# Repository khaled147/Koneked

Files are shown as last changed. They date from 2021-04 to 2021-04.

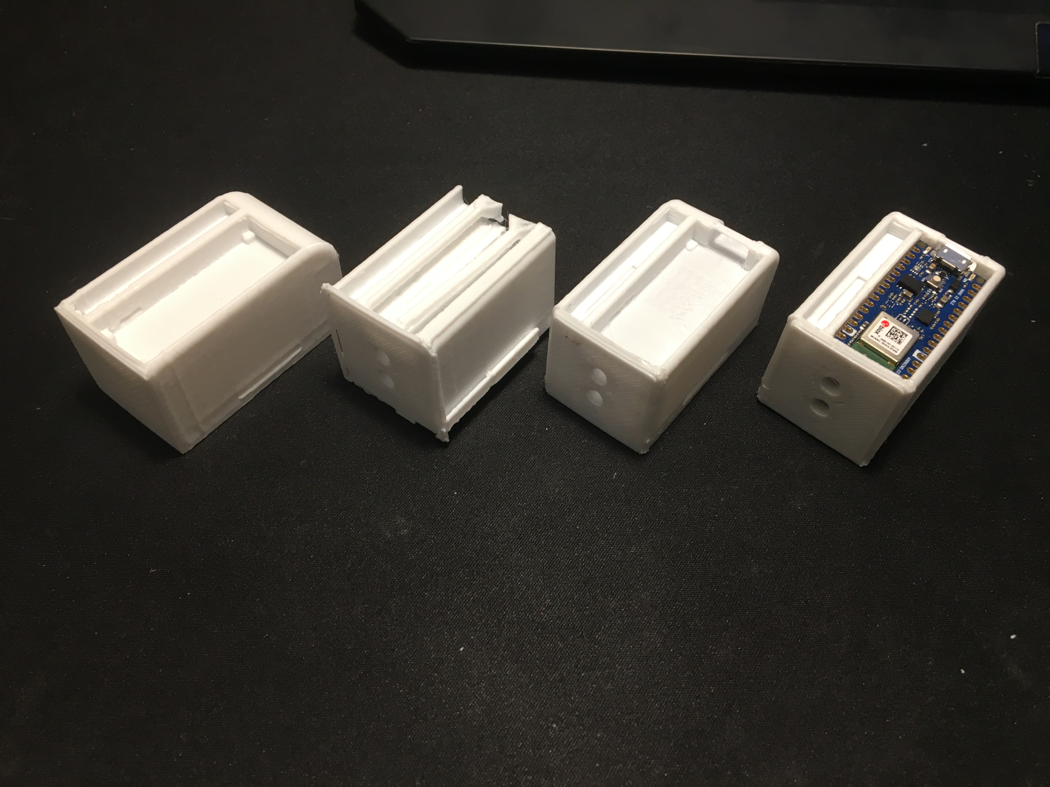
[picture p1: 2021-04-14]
Koneked_Case/KonekedCase_Version2/images/V2_C.JPG

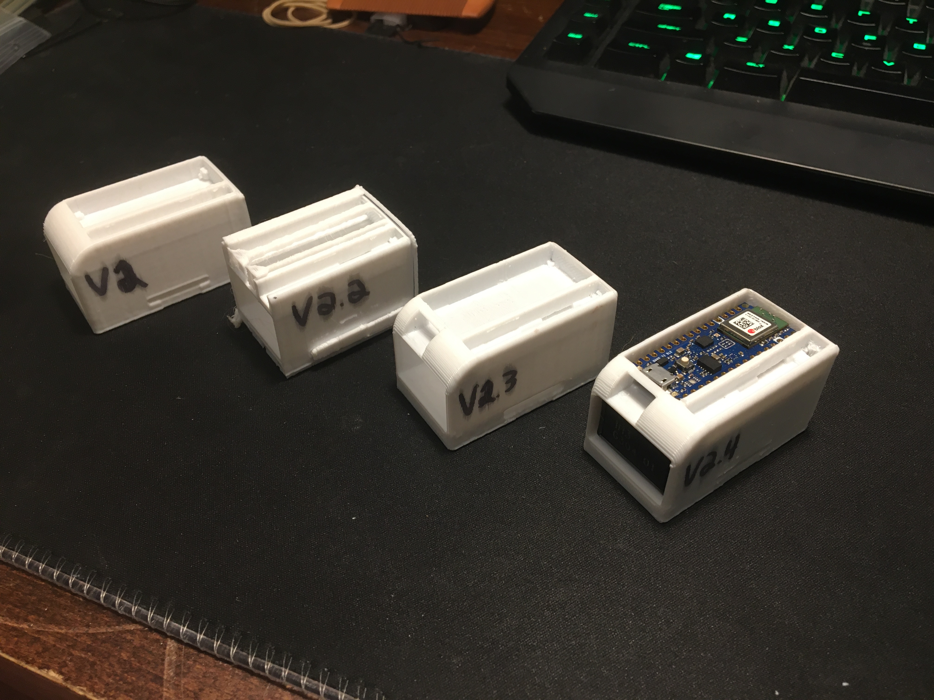
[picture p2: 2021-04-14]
Koneked_Case/KonekedCase_Version2/images/V2_A.JPG

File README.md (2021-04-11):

# Koneked
Project for ENEL 400 at the University of Calgary

**Release** </br>
The App allows connection to the Koneked Hearing Aid device. The user can speak directly to the phone's mic, plug in a microphone or even a bluetooth transmitter. The app will convert the speech to text and send the text to the device to convert it to our very own altered morse code.

**Ideas:**
1. Use the PDM microphone on Arduino Nano 33 BLE Sense to record to a WAV file (*Unable to get it to work, but here are some notes*)
 	- ~~Probably need to implement a FIR Decimation filter (https://www.theunterminatedstring.com/probing-pdm/)~~ (*only necessary if need to convert from PDM to PCM*)
 	- It seems like the PDM microphone on the Arduino Nano 33 BLE Sense outputs audio in PCM (https://forum.arduino.cc/index.php?topic=678154.0)
 	- Important to understand how digital audio works (https://manual.audacityteam.org/man/digital_audio.html)
 	- It seems like this has been implemented on the Teensyduino (https://forum.arduino.cc/index.php?topic=550869.0)
 	- Audio recording with Arduino seems to be a pain (https://forum.arduino.cc/index.php?topic=561135.0)
 	- Located in the Arduino folder
 	- **New Idea to Try Out:** Use AutoAnalogAudio by TMRh20 (https://github.com/TMRh20/AutoAnalogAudio)
 	- **Another Idea to Try Out:** Determine how to use the ArduinoSound library
2.  Implemented 2 Tensorflow models for STT - Notes:
 	- Works offline
 	- Very low accurracy
 	- 1st Model Resource: https://create.arduino.cc/projecthub/alankrantas/eloquenttinyml-easier-voice-classifier-on-nano-33-ble-sense-ebb81e
 	- 2nd Model Resource: https://eloquentarduino.github.io/2020/08/better-word-classification-with-arduino-33-ble-sense-and-machine-learning/
 	- Both are located in the Arduino folder
3. Implemented STT using python - Notes:
 	- Located in the Python folder
 	- Language: Uses online APIs - currently working with the Microsoft Bing Voice Recognition (https://pypi.org/project/SpeechRecognition/)
 	- Offline_SST: Uses offline API - currently working with Mozilla DeepSpeech (https://github.com/mozilla/DeepSpeech)
 	- **Issue:** Both Require WAV file --> ~~**Solution:** Buy a microphone wired to the Arduino (https://www.instructables.com/Make-Your-Own-Spy-Bug-Arduino-Voice-Recorder/)~~ (Did not work as TMRpcm only works on Arduino Uno and Arduino MEGA)
4. **Implemented Idea:** Record audio from the mobile device itself using the app
 	- Can then connect a wired microphone or a bluetooth transmitter (ex. https://www.nuheara.com/ca/products/bluetooth-transmitter/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)
 	- Android has its own speechRecognizer class (https://betterprogramming.pub/implement-continuous-speech-recognition-on-android-1dd2f4b562fd)
5. **Potential Idea to Try Out:** Connect a bluetooth microphone concurrently with the bluetooth connection with the Arudino using the app
6. Battery Operation (4.5V to 21 V):
 	- Broke open portable charger
 	- Button battery (https://forum.arduino.cc/index.php?topic=657082.0)
 	- LiPo Battery (https://www.hackster.io/ebaera/nano-33-lipo-adapter-nano9jira-6e78a1)
7. I/O pins produce 0.7 mA but require ~~80mA~~ (around 50-60 mA after testing on my ammeter)
 	- Design a transistor switch with SN8050 (β = 110 and Vbe = 0.73V) or PN2222 with the 3.3 output switch on the Nano BLE 33 sense (https://www.electronicshub.org/transistor-as-a-switch/)
    
**Features:**

Virtual Python Environment:
 - Located in the Python folder
 - Installed with required libraries to run all python scripts in this repository
 - https://packaging.python.org/tutorials/installing-packages/

**Resources:**
 - Allows designing of TIR filters quickly: http://t-filter.engineerjs.com/
 - Writing python files in Android: https://www.youtube.com/watch?v=m_vV5ZKBuNg&ab_channel=ProgrammingFever
 - Working with audio files: https://realpython.com/python-speech-recognition/#working-with-audio-files
 - Implement Python and Java together: https://chaquo.com/chaquopy/doc/current/android.html
 - Beginner's guide to Bluetooth Low Power: https://devzone.nordicsemi.com/nordic/short-range-guides/b/bluetooth-low-energy/posts/ble-services-a-beginners-tutorial

The latter allows writing python code with Java but requires NDK tools (Files->Settings->Appearance & Behavior->System Settings->Android SDK):


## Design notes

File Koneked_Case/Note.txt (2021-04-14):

---
Models made using Solidworks 2020
Gcode made with Slic3r 2020

OTHER
----------
Different Versions for Rechargable power supply taken from cheap 2600mmAh block

Decided to go with 9V battery as it is compact...

Daughter Circuit to be added in empty space in in CaseVersion2 as 
Arduino did not output enough current to buzzers...

---
MoGrona - 2021

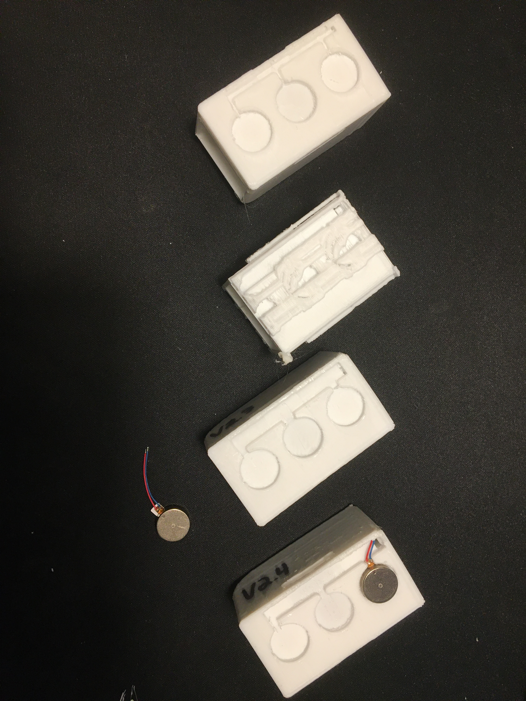
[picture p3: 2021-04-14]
Koneked_Case/KonekedCase_Version2/images/V2_D.JPG

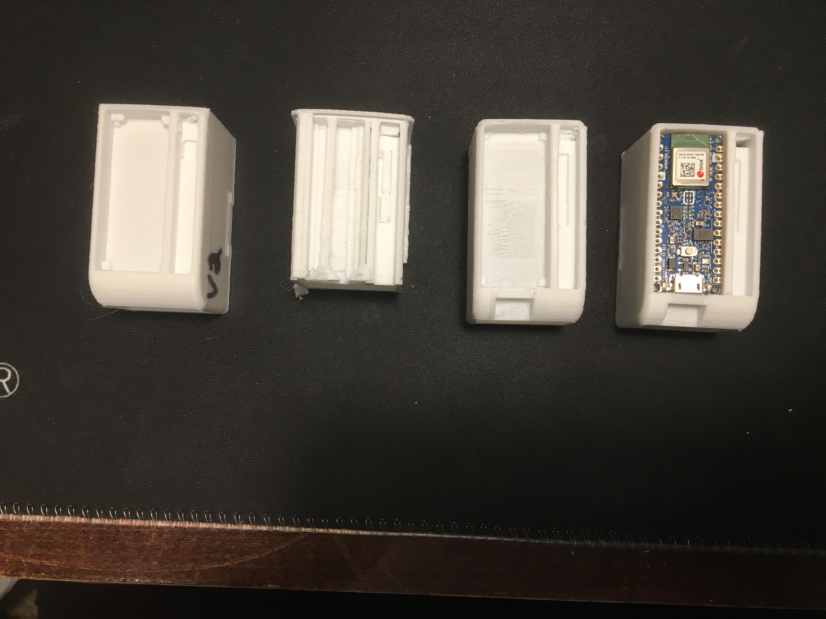
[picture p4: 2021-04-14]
Koneked_Case/KonekedCase_Version2/images/V2_B.JPG

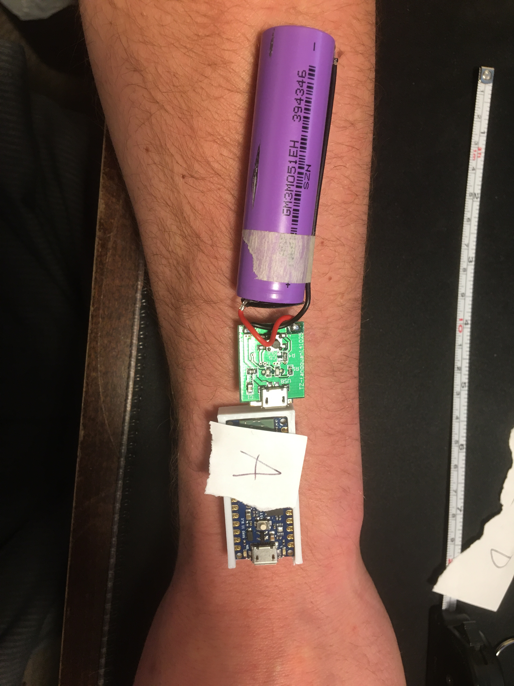
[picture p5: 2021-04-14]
Koneked_Case/Other/Koneked_W.JPG

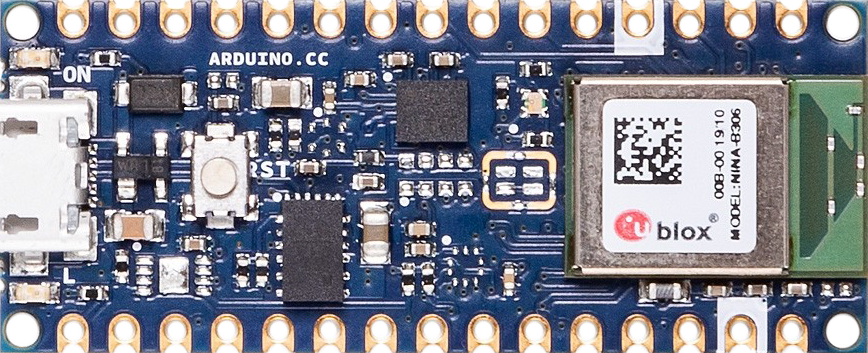
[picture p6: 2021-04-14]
Koneked_Case/Nano33BLE_Stock/Nano33BLEfront.png

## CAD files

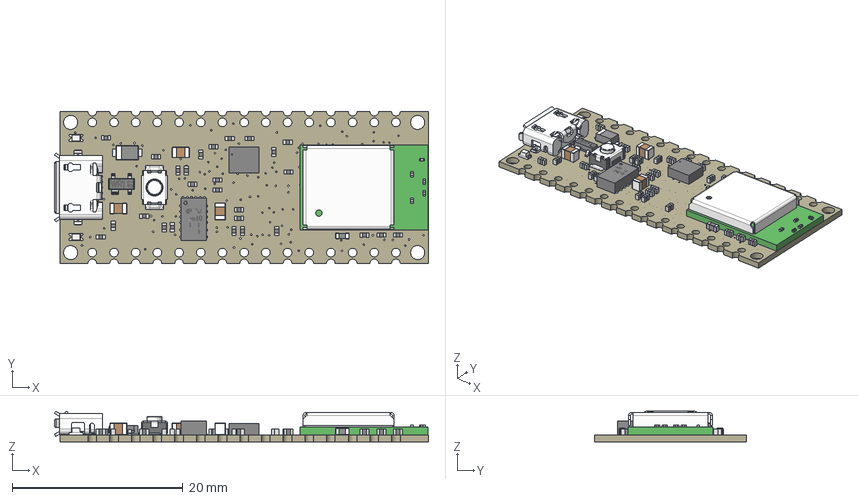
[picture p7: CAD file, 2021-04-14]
Koneked_Case/Nano33BLE_Stock/Nano33BLE.step
43.8 x 17.8 x 3.57 mm
Board (1)
LSM9DS1TR_LGA-24_3X3P5X1_STM v1
ZX62-AB-5PA (1)
IoT_HSMG-C190 LED v1 x 2
IoT_MPM3610 Step-Down Module v1
User Library-arduino_nano_reset core
User Library-arduino_nano_reset shell
RC0402FR-071KL RC0402N_YAG v1 x 27
BLM18EG101TN1D v1
C0805C472KDRACTU v1 x 3
PMEG6020AELRX v1
IoT_PRTR5V0U2X Protection Diode v1
NINA-B306-00B-00--3DModel-STEP-56544 v1

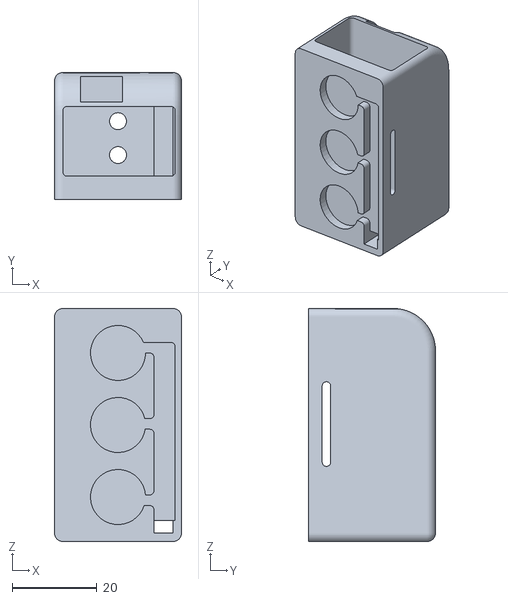
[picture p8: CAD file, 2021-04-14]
Koneked_Case/KonekedCase_Version2/files/Version2.4.STL
30.0 x 30.0 x 55.0

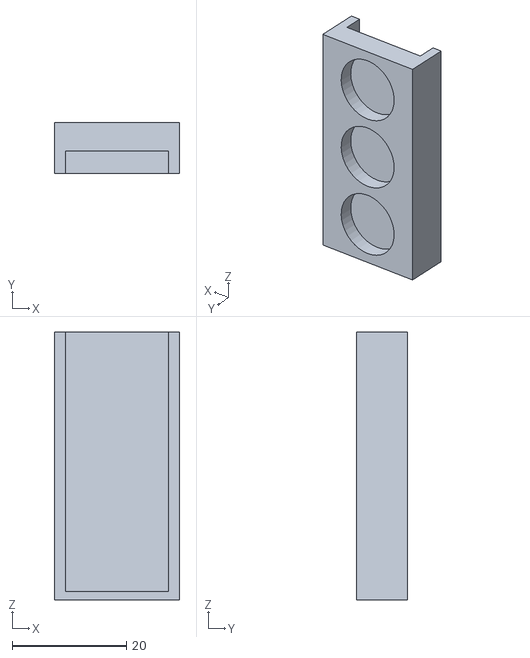
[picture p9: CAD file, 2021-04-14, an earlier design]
Koneked_Case/KonekedCase_Version1/files/V1.2.STL
22.0 x 9.00 x 47.0

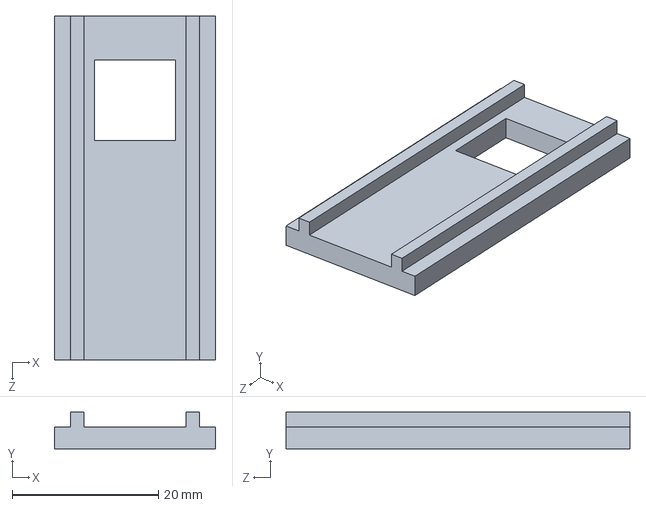
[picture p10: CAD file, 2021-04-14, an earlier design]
Koneked_Case/KonekedCase_Version1/files/Lid.SLDPRT
22.0 x 5.00 x 47.0 mm

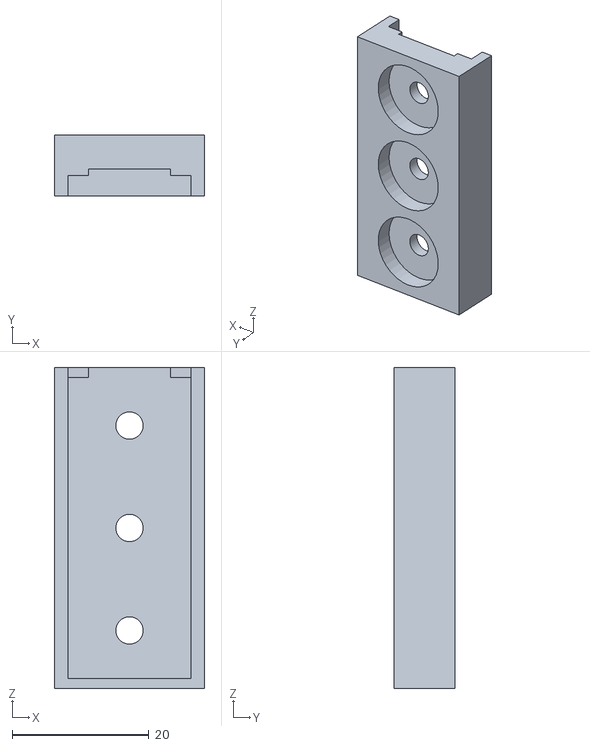
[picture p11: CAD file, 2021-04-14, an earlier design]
Koneked_Case/KonekedCase_Version1/files/V1.3.STL
22.0 x 9.00 x 47.0

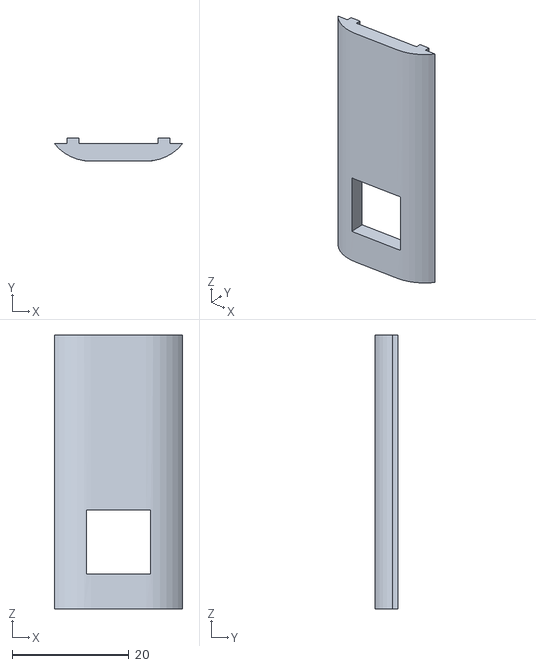
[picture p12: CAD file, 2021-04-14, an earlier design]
Koneked_Case/KonekedCase_Version1/files/Lid2.STL
22.0 x 4.00 x 47.0

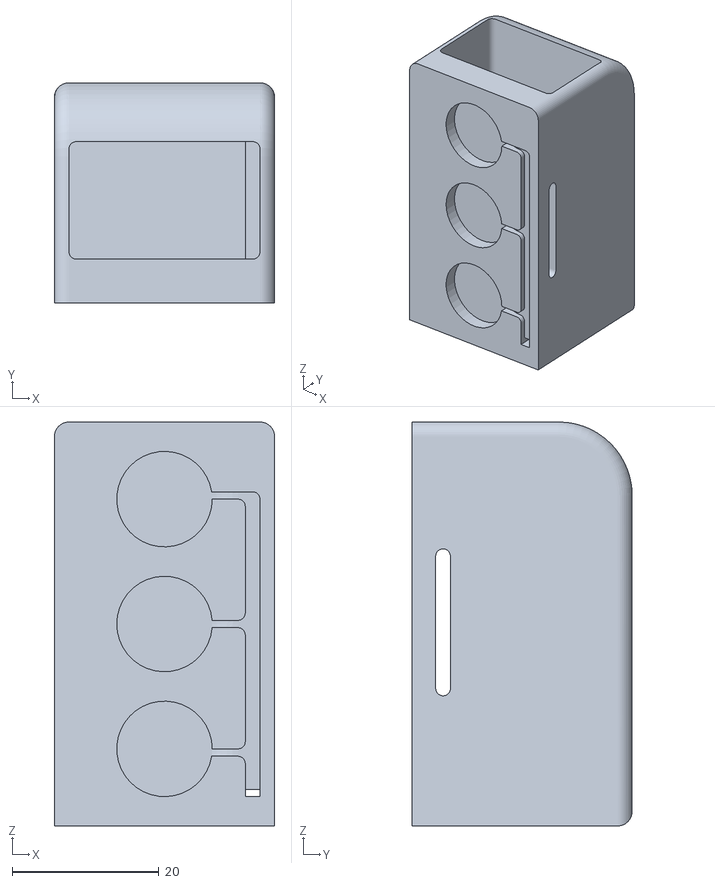
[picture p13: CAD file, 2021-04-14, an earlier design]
Koneked_Case/KonekedCase_Version2/files/Version2.2.STL
30.0 x 30.0 x 55.0

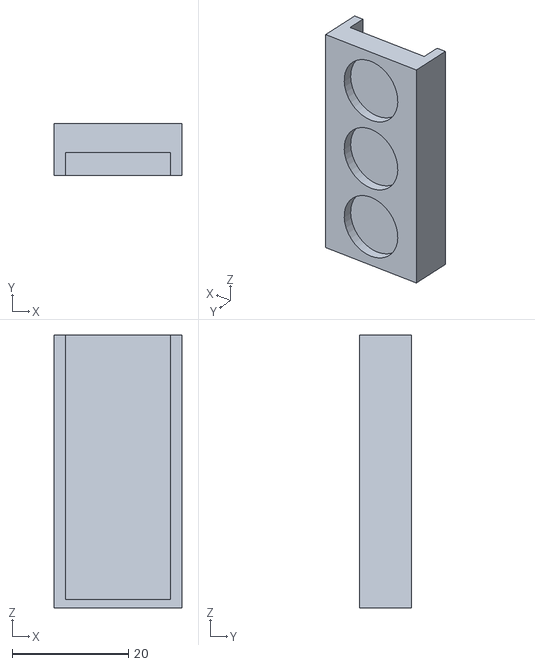
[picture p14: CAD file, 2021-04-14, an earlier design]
Koneked_Case/KonekedCase_Version1/files/V1.1.STL
22.0 x 9.00 x 47.0

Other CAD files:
Koneked_Case/KonekedCase_Version2/files/KonekedCase_9Volt.SLDPRT
Koneked_Case/KonekedCase_Version2/files/Version2.3.STL
Koneked_Case/KonekedCase_Version2/files/Version2.1.STL
Koneked_Case/KonekedCase_Version1/files/Part1.SLDPRT
Koneked_Case/KonekedCase_Version1/files/Lid.STL
Koneked_Case/Nano33BLE_Stock/Nano33BLE.SLDASM

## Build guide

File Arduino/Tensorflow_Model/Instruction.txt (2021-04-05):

Follow the folowing link:
https://create.arduino.cc/projecthub/alankrantas/eloquenttinyml-easier-voice-classifier-on-nano-33-ble-sense-ebb81e

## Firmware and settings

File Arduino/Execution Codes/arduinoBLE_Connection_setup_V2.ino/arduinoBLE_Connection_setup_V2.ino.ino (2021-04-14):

// ArduinoBLE Connection Setup V2

// This version does not use the onboard microphone
// Refer to first version for additional notes and resources

#include <ArduinoBLE.h>

#define NAME_OF_PERIPHERAL "BLE Koneked Device"

// Create a service to expose our service to BLE Central Devices
BLEService Koneked("181A");

// Setup the incoming data characteristic (RX).
const int RX_BUFFER_SIZE = 256;
bool RX_BUFFER_FIXED_LENGTH = false;

// RX / TX Characteristics (Receive/Transmit Data)
BLECharacteristic rxChar("2A3D", BLEWriteWithoutResponse | BLEWrite, RX_BUFFER_SIZE, RX_BUFFER_FIXED_LENGTH);
BLEByteCharacteristic txChar("2A58", BLERead | BLENotify | BLEBroadcast);
BLEDescriptor txDescriptor("2902", "ABC1");

// Dit and Dah timings for altered morse code conversion
#define DIT 100
#define DAH DIT*3

#define  MOTOR_1_PIN 12
#define  MOTOR_2_PIN 3
#define  MOTOR_3_PIN 2

void setup() {
  // Start serial
  Serial.begin(9600);

  // Prepare LED pins
  pinMode(LED_BUILTIN, OUTPUT);
  pinMode(LEDR, OUTPUT);
  pinMode(LEDG, OUTPUT);

  // Prepare Motor pins
  pinMode(MOTOR_1_PIN, OUTPUT);
  pinMode(MOTOR_2_PIN, OUTPUT);
  pinMode(MOTOR_3_PIN, OUTPUT);

  // Start BLE.
  startBLE();

  // Create BLE service and characteristics
  // Change advertised BLE Characteristics names
  BLE.setLocalName(NAME_OF_PERIPHERAL);
  BLE.setDeviceName(NAME_OF_PERIPHERAL);          // this sets Characteristic 0x2a00 of Service 0x1800
  // Service 0x1800 is the Generic Access Profile
  // Characteristic 0x2a00 is the Device Name
  // Characteristic 0x2a01 is the "Appearance"
  BLE.setAppearance(192);                       // BLE_APPEARANCE_GENERIC_WATCH
  // Appearance can be determined using the following: https://infocenter.nordicsemi.com/index.jsp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
  BLE.setAdvertisedService(Koneked);
  txChar.addDescriptor(txDescriptor);
  Koneked.addCharacteristic(rxChar);
  Koneked.addCharacteristic(txChar);
  BLE.addService(Koneked);

  // Bluetooth LE connection handlers
  BLE.setEventHandler(BLEConnected, onBLEConnected);
  BLE.setEventHandler(BLEDisconnected, onBLEDisconnected);

  // Event driven reads.
  rxChar.setEventHandler(BLEWritten, onRxCharValueUpdate);

  // Print out full UUID and MAC address.
  Serial.println("Peripheral advertising info: ");
  Serial.print("Name: ");
  Serial.println(NAME_OF_PERIPHERAL);
  Serial.print("MAC: ");
  Serial.println(BLE.address());
  Serial.print("Service UUID: ");
  Serial.println(Koneked.uuid());
  Serial.print("rxCharacteristic UUID: ");
  Serial.println(rxChar.uuid());
  Serial.print("txCharacteristics UUID: ");
  Serial.println(txChar.uuid());

  Serial.println("Bluetooth device active, waiting for connections...");;

  // Advertise to the world so device can be found
  BLE.advertise();
}

void loop()
{
  BLEDevice central = BLE.central();
  if (central) {
    // Data can be sent through here
    while (central.connected()) {
      connectedLight();
      //txChar.writeValue();
    }
    disconnectedLight();
  } else {
    disconnectedLight();
  }
}

/*
    BLUETOOTH
*/
void startBLE() {
  if (!BLE.begin())
  {
    Serial.println("starting BLE failed!");
    while (1);
  }
}

void onRxCharValueUpdate(BLEDevice central, BLECharacteristic characteristic) {
  // central wrote new value to characteristic, update LED
  Serial.print("Characteristic event, read: ");
  byte tmp[256];
  int dataLength = rxChar.readValue(tmp, 256);

  for (int i = 0; i < dataLength; i++) {
    Serial.print((char)tmp[i]);
  }
  Serial.println();
  Serial.print("Value length = ");
  Serial.println(rxChar.valueLength());

  if ((char)tmp[0] == 'U' && rxChar.valueLength() == 1) {
    digitalWrite(MOTOR_1_PIN, HIGH);     //  make sure motor is on
    Serial.println("Motor 1 On");
    delay(500);
    digitalWrite(MOTOR_1_PIN, LOW);     //  make sure motor is NOT on

    digitalWrite(MOTOR_2_PIN, HIGH);     //  make sure motor is on
    Serial.println("Motor 2 On");
    delay(500);
    digitalWrite(MOTOR_2_PIN, LOW);     //  make sure motor is NOT on

    digitalWrite(MOTOR_3_PIN, HIGH);     //  make sure motor is on
    Serial.println("Motor 3 On");
    delay(500);
    digitalWrite(MOTOR_3_PIN, LOW);     //  make sure motor is NOT on
  }
  else {
    for (int i = 0; i < dataLength; i++) {
      characterToVibration((char)tmp[i]);
    }
  }
}

void onBLEConnected(BLEDevice central) {
  Serial.print("Connected event, central: ");
  Serial.println(central.address());
  connectedLight();
  digitalWrite(MOTOR_1_PIN, LOW);     //  make sure motor is NOT on
  digitalWrite(MOTOR_2_PIN, LOW);     //  make sure motor is NOT on
  digitalWrite(MOTOR_3_PIN, LOW);     //  make sure motor is NOT on
}

void onBLEDisconnected(BLEDevice central) {
  Serial.print("Disconnected event, central: ");
  Serial.println(central.address());
  disconnectedLight();
  digitalWrite(MOTOR_1_PIN, LOW);     //  make sure motor is NOT on
  digitalWrite(MOTOR_2_PIN, LOW);     //  make sure motor is NOT on
  digitalWrite(MOTOR_3_PIN, LOW);     //  make sure motor is NOT on
}

/*
   LEDS
*/
void connectedLight() {
  digitalWrite(LEDG, LOW);
  digitalWrite(LEDR, HIGH);
}


void disconnectedLight() {
  digitalWrite(LEDG, HIGH);
  digitalWrite(LEDR, LOW);
}

/*
   CONVERTION TO ALTERED MORSE CODE
*/

void characterToVibration(char x) {
  Serial.println(x);
  if (x == ' ') {
    digitalWrite(MOTOR_3_PIN, HIGH);
    delay(DIT);
    digitalWrite(MOTOR_3_PIN, LOW);
    delay(DIT / 2);
    digitalWrite(MOTOR_3_PIN, HIGH);
    delay(DIT);
  } else if (x == 'e' || x == 'E') {
    digitalWrite(MOTOR_1_PIN, HIGH);
    digitalWrite(MOTOR_3_PIN, HIGH);
    delay(DIT);
  } else if (x == 'i' || x == 'I') {
    digitalWrite(MOTOR_2_PIN, HIGH);
    digitalWrite(MOTOR_3_PIN, HIGH);
    delay(DIT);
  } else if (x == 't' || x == 'T') {
    digitalWrite(MOTOR_1_PIN, HIGH);
    delay(DIT);
    digitalWrite(MOTOR_1_PIN, LOW);
    delay(DIT / 2);
    digitalWrite(MOTOR_1_PIN, HIGH);
    digitalWrite(MOTOR_3_PIN, HIGH);
    delay(DIT);
  } else if (x == 'a' || x == 'A') {
    digitalWrite(MOTOR_2_PIN, HIGH);
    delay(DIT);
    digitalWrite(MOTOR_2_PIN, LOW);
    delay(DIT / 2);
    digitalWrite(MOTOR_2_PIN, HIGH);
    digitalWrite(MOTOR_3_PIN, HIGH);
    delay(DIT);
  } else if (x == 'n' || x == 'N') {
    digitalWrite(MOTOR_1_PIN, HIGH);
    digitalWrite(MOTOR_3_PIN, HIGH);
    delay(DIT);
    digitalWrite(MOTOR_3_PIN, LOW);
    delay(DAH - DIT);
  } else if (x == 's' || x == 'S') {
    digitalWrite(MOTOR_2_PIN, HIGH);
    digitalWrite(MOTOR_3_PIN, HIGH);
    delay(DIT);
    digitalWrite(MOTOR_3_PIN, LOW);
    delay(DAH - DIT);
  } else if (x == 'd' || x == 'D') {
    digitalWrite(MOTOR_1_PIN, HIGH);
    delay(DIT);
    digitalWrite(MOTOR_1_PIN, LOW);
    delay(DIT / 2);
    digitalWrite(MOTOR_1_PIN, HIGH);
    digitalWrite(MOTOR_3_PIN, HIGH);
    delay(DIT);
    digitalWrite(MOTOR_3_PIN, LOW);
    delay(DAH - DIT);
  } else if (x == 'h' || x == 'H') {
    digitalWrite(MOTOR_2_PIN, HIGH);
    delay(DIT);
    digitalWrite(MOTOR_2_PIN, LOW);
    delay(DIT / 2);
    digitalWrite(MOTOR_2_PIN, HIGH);
    digitalWrite(MOTOR_3_PIN, HIGH);
    delay(DIT);
    digitalWrite(MOTOR_3_PIN, LOW);
    delay(DAH - DIT);
  } else if (x == 'm' || x == 'M') {
    digitalWrite(MOTOR_1_PIN, HIGH);
    delay(DAH);
    digitalWrite(MOTOR_1_PIN, LOW);
    delay(DIT / 2);
    digitalWrite(MOTOR_1_PIN, HIGH);
    digitalWrite(MOTOR_3_PIN, HIGH);
    delay(DIT);
  } else if (x == 'r' || x == 'R') {
    digitalWrite(MOTOR_2_PIN, HIGH);
    delay(DAH);
    digitalWrite(MOTOR_2_PIN, LOW);
    delay(DIT / 2);
    digitalWrite(MOTOR_2_PIN, HIGH);
    digitalWrite(MOTOR_3_PIN, HIGH);
    delay(DIT);
  } else if (x == 'u' || x == 'U') {
    digitalWrite(MOTOR_1_PIN, HIGH);
    delay(DIT);
    digitalWrite(MOTOR_1_PIN, LOW);
    delay(DIT / 2);
    digitalWrite(MOTOR_1_PIN, HIGH);
    delay(DIT);
    digitalWrite(MOTOR_1_PIN, LOW);
    delay(DIT / 2);
    digitalWrite(MOTOR_1_PIN, HIGH);
    digitalWrite(MOTOR_3_PIN, HIGH);
    delay(DIT);
  } else if (x == 'b' || x == 'B') {
    digitalWrite(MOTOR_2_PIN, HIGH);
    delay(DIT);
    digitalWrite(MOTOR_2_PIN, LOW);
    delay(DIT / 2);
    digitalWrite(MOTOR_2_PIN, HIGH);
    delay(DIT);
    digitalWrite(MOTOR_2_PIN, LOW);
    delay(DIT / 2);
    digitalWrite(MOTOR_2_PIN, HIGH);
    digitalWrite(MOTOR_3_PIN, HIGH);
    delay(DIT);
  } else if (x == 'f' || x == 'F') {
    digitalWrite(MOTOR_1_PIN, HIGH);
    delay(DAH);
    digitalWrite(MOTOR_1_PIN, LOW);
    delay(DIT / 2);
    digitalWrite(MOTOR_1_PIN, HIGH);
    delay(DIT);
    digitalWrite(MOTOR_1_PIN, LOW);
    delay(DIT / 2);
    digitalWrite(MOTOR_1_PIN, HIGH);
    digitalWrite(MOTOR_3_PIN, HIGH);
    delay(DIT);
  } else if (x == 'g' || x == 'G') {
    digitalWrite(MOTOR_2_PIN, HIGH);
    delay(DAH);
    digitalWrite(MOTOR_2_PIN, LOW);
    delay(DIT / 2);
    digitalWrite(MOTOR_2_PIN, HIGH);
    delay(DIT);
    digitalWrite(MOTOR_2_PIN, LOW);
    delay(DIT / 2);
    digitalWrite(MOTOR_2_PIN, HIGH);
    digitalWrite(MOTOR_3_PIN, HIGH);
    delay(DIT);
  } else if (x == 'k' || x == 'K') {
    digitalWrite(MOTOR_1_PIN, HIGH);
    delay(DIT);
    digitalWrite(MOTOR_1_PIN, LOW);
    delay(DIT / 2);
    digitalWrite(MOTOR_1_PIN, HIGH);
    delay(DIT);
    digitalWrite(MOTOR_1_PIN, LOW);
    delay(DIT / 2);
    digitalWrite(MOTOR_1_PIN, HIGH);
    delay(DIT);
    digitalWrite(MOTOR_1_PIN, LOW);
    delay(DIT / 2);
    digitalWrite(MOTOR_1_PIN, HIGH);
    digitalWrite(MOTOR_3_PIN, HIGH);
    delay(DIT);
  } else if (x == 'l' || x == 'L') {
    digitalWrite(MOTOR_2_PIN, HIGH);
    delay(DIT);
    digitalWrite(MOTOR_2_PIN, LOW);
    delay(DIT / 2);
    digitalWrite(MOTOR_2_PIN, HIGH);
    delay(DIT);
    digitalWrite(MOTOR_2_PIN, LOW);
    delay(DIT / 2);
    digitalWrite(MOTOR_2_PIN, HIGH);
    delay(DIT);
    digitalWrite(MOTOR_2_PIN, LOW);
    delay(DIT / 2);
    digitalWrite(MOTOR_2_PIN, HIGH);
    digitalWrite(MOTOR_3_PIN, HIGH);
    delay(DIT);
  } else if (x == 'v' || x == 'V') {
    digitalWrite(MOTOR_1_PIN, HIGH);
    delay(DAH);
    digitalWrite(MOTOR_1_PIN, LOW);
    delay(DIT / 2);
    digitalWrite(MOTOR_1_PIN, HIGH);
    digitalWrite(MOTOR_3_PIN, HIGH);
    delay(DIT);
    digitalWrite(MOTOR_3_PIN, LOW);
    delay(DAH - DIT);
  } else if (x == 'w' || x == 'W') {
    digitalWrite(MOTOR_2_PIN, HIGH);
    delay(DAH);
    digitalWrite(MOTOR_2_PIN, LOW);
    delay(DIT / 2);
    digitalWrite(MOTOR_2_PIN, HIGH);
    digitalWrite(MOTOR_3_PIN, HIGH);
    delay(DIT);
    digitalWrite(MOTOR_3_PIN, LOW);
    delay(DAH - DIT);
  } else if (x == '5') {
    digitalWrite(MOTOR_1_PIN, HIGH);
    delay(DIT);
    digitalWrite(MOTOR_1_PIN, LOW);
    delay(DIT / 2);
    digitalWrite(MOTOR_1_PIN, HIGH);
    delay(DAH);
    digitalWrite(MOTOR_1_PIN, LOW);
    delay(DIT / 2);
    digitalWrite(MOTOR_1_PIN, HIGH);
    digitalWrite(MOTOR_3_PIN, HIGH);
    delay(DIT);
  } else if (x == 'c' || x == 'C') {
    digitalWrite(MOTOR_2_PIN, HIGH);
    delay(DIT);
    digitalWrite(MOTOR_2_PIN, LOW);
    delay(DIT / 2);
    digitalWrite(MOTOR_2_PIN, HIGH);
    delay(DAH);
    digitalWrite(MOTOR_2_PIN, LOW);
    delay(DIT / 2);
    digitalWrite(MOTOR_2_PIN, HIGH);
    digitalWrite(MOTOR_3_PIN, HIGH);
    delay(DIT);
  } else if (x == 'o' || x == 'O') {
    digitalWrite(MOTOR_1_PIN, HIGH);
    delay(DIT);
    digitalWrite(MOTOR_1_PIN, LOW);
    delay(DIT / 2);
    digitalWrite(MOTOR_1_PIN, HIGH);
    delay(DIT);
    digitalWrite(MOTOR_1_PIN, LOW);
    delay(DIT / 2);
    digitalWrite(MOTOR_1_PIN, HIGH);
    digitalWrite(MOTOR_3_PIN, HIGH);
    delay(DIT);
    digitalWrite(MOTOR_3_PIN, LOW);
    delay(DAH - DIT);
  } else if (x == 'p' || x == 'P') {
    digitalWrite(MOTOR_2_PIN, HIGH);
    delay(DIT);
    digitalWrite(MOTOR_2_PIN, LOW);
    delay(DIT / 2);
    digitalWrite(MOTOR_2_PIN, HIGH);
    delay(DIT);
    digitalWrite(MOTOR_2_PIN, LOW);
    delay(DIT / 2);
    digitalWrite(MOTOR_2_PIN, HIGH);
    digitalWrite(MOTOR_3_PIN, HIGH);
    delay(DIT);
    digitalWrite(MOTOR_3_PIN, LOW);
    delay(DAH - DIT);
  } else if (x == 'x' || x == 'X') {
    digitalWrite(MOTOR_1_PIN, HIGH);
    delay(DAH);
    digitalWrite(MOTOR_1_PIN, LOW);
    delay(DIT / 2);
    digitalWrite(MOTOR_1_PIN, HIGH);
    delay(DIT);
    digitalWrite(MOTOR_1_PIN, LOW);
    delay(DIT / 2);
    digitalWrite(MOTOR_1_PIN, HIGH);
    delay(DIT);
    digitalWrite(MOTOR_1_PIN, LOW);
    delay(DIT / 2);
    digitalWrite(MOTOR_1_PIN, HIGH);
    digitalWrite(MOTOR_3_PIN, HIGH);
    delay(DIT);
  } else if (x == 'z' || x == 'Z') {
    digitalWrite(MOTOR_2_PIN, HIGH);
    delay(DAH);
    digitalWrite(MOTOR_2_PIN, LOW);
    delay(DIT / 2);
    digitalWrite(MOTOR_2_PIN, HIGH);
    delay(DIT);
    digitalWrite(MOTOR_2_PIN, LOW);
    delay(DIT / 2);
    digitalWrite(MOTOR_2_PIN, HIGH);
    delay(DIT);
    digitalWrite(MOTOR_2_PIN, LOW);
    delay(DIT / 2);
    digitalWrite(MOTOR_2_PIN, HIGH);
    digitalWrite(MOTOR_3_PIN, HIGH);
    delay(DIT);
  } else if (x == '4') {
    digitalWrite(MOTOR_1_PIN, HIGH);
    delay(DIT);
    digitalWrite(MOTOR_1_PIN, LOW);
    delay(DIT / 2);
    digitalWrite(MOTOR_1_PIN, HIGH);
    delay(DAH);
    digitalWrite(MOTOR_1_PIN, LOW);
    delay(DIT / 2);
    digitalWrite(MOTOR_1_PIN, HIGH);
    delay(DIT);
    digitalWrite(MOTOR_1_PIN, LOW);
    delay(DIT / 2);
    digitalWrite(MOTOR_1_PIN, HIGH);
    digitalWrite(MOTOR_3_PIN, HIGH);
    delay(DIT);
  } else if (x == '6') {
    digitalWrite(MOTOR_2_PIN, HIGH);
    delay(DIT);
    digitalWrite(MOTOR_2_PIN, LOW);
    delay(DIT / 2);
    digitalWrite(MOTOR_2_PIN, HIGH);
    delay(DAH);
    digitalWrite(MOTOR_2_PIN, LOW);
    delay(DIT / 2);
    digitalWrite(MOTOR_2_PIN, HIGH);
    delay(DIT);
    digitalWrite(MOTOR_2_PIN, LOW);
    delay(DIT / 2);
    digitalWrite(MOTOR_2_PIN, HIGH);
    digitalWrite(MOTOR_3_PIN, HIGH);
    delay(DIT);
  } else if (x == 'j' || x == 'J') {
    digitalWrite(MOTOR_1_PIN, HIGH);
    delay(DIT);
    digitalWrite(MOTOR_1_PIN, LOW);
    delay(DIT / 2);
    digitalWrite(MOTOR_1_PIN, HIGH);
    delay(DIT);
    digitalWrite(MOTOR_1_PIN, LOW);
    delay(DIT / 2);
    digitalWrite(MOTOR_1_PIN, HIGH);
    delay(DAH);
    digitalWrite(MOTOR_1_PIN, LOW);
    delay(DIT / 2);
    digitalWrite(MOTOR_1_PIN, HIGH);
    digitalWrite(MOTOR_3_PIN, HIGH);
    delay(DIT);
  } else if (x == 'q' || x == 'Q') {
    digitalWrite(MOTOR_2_PIN, HIGH);
    delay(DIT);
    digitalWrite(MOTOR_2_PIN, LOW);
    delay(DIT / 2);
    digitalWrite(MOTOR_2_PIN, HIGH);
    delay(DIT);
    digitalWrite(MOTOR_2_PIN, LOW);
    delay(DIT / 2);
    digitalWrite(MOTOR_2_PIN, HIGH);
    delay(DAH);
    digitalWrite(MOTOR_2_PIN, LOW);
    delay(DIT / 2);
    digitalWrite(MOTOR_2_PIN, HIGH);
    digitalWrite(MOTOR_3_PIN, HIGH);
    delay(DIT);
  } else if (x == 'y' || x == 'Y') {
    digitalWrite(MOTOR_1_PIN, HIGH);
    delay(DIT);
    digitalWrite(MOTOR_1_PIN, LOW);
    delay(DIT / 2);
    digitalWrite(MOTOR_1_PIN, HIGH);
    delay(DIT);
    digitalWrite(MOTOR_1_PIN, LOW);
    delay(DIT / 2);
    digitalWrite(MOTOR_1_PIN, HIGH);
    delay(DIT);
    digitalWrite(MOTOR_1_PIN, LOW);
    delay(DIT / 2);
    digitalWrite(MOTOR_1_PIN, HIGH);
    digitalWrite(MOTOR_3_PIN, HIGH);
    delay(DIT);
    digitalWrite(MOTOR_3_PIN, LOW);
    delay(DAH - DIT);
  } else if (x == '3') {
    digitalWrite(MOTOR_2_PIN, HIGH);
    delay(DIT);
    digitalWrite(MOTOR_2_PIN, LOW);
    delay(DIT / 2);
    digitalWrite(MOTOR_2_PIN, HIGH);
    delay(DIT);
    digitalWrite(MOTOR_2_PIN, LOW);
    delay(DIT / 2);
    digitalWrite(MOTOR_2_PIN, HIGH);
    delay(DIT);
    digitalWrite(MOTOR_2_PIN, LOW);
    delay(DIT / 2);
    digitalWrite(MOTOR_2_PIN, HIGH);
    digitalWrite(MOTOR_3_PIN, HIGH);
    delay(DIT);
    digitalWrite(MOTOR_3_PIN, LOW);
    delay(DAH - DIT);
  } else if (x == '7') {
    digitalWrite(MOTOR_1_PIN, HIGH);
    delay(DAH);
    digitalWrite(MOTOR_1_PIN, LOW);
    delay(DIT / 2);
    digitalWrite(MOTOR_1_PIN, HIGH);
    delay(DAH);
    digitalWrite(MOTOR_1_PIN, LOW);
    delay(DIT / 2);
    digitalWrite(MOTOR_1_PIN, HIGH);
    digitalWrite(MOTOR_3_PIN, HIGH);
    delay(DIT);
  } else if (x == '2') {
    digitalWrite(MOTOR_2_PIN, HIGH);
    delay(DAH);
    digitalWrite(MOTOR_2_PIN, LOW);
    delay(DIT / 2);
    digitalWrite(MOTOR_2_PIN, HIGH);
    delay(DAH);
    digitalWrite(MOTOR_2_PIN, LOW);
    delay(DIT / 2);
    digitalWrite(MOTOR_2_PIN, HIGH);
    digitalWrite(MOTOR_3_PIN, HIGH);
    delay(DIT);
  } else if (x == '8') {
    digitalWrite(MOTOR_1_PIN, HIGH);
    delay(DAH);
    digitalWrite(MOTOR_1_PIN, LOW);
    delay(DIT / 2);
    digitalWrite(MOTOR_1_PIN, HIGH);
    delay(DIT);
    digitalWrite(MOTOR_1_PIN, LOW);
    delay(DIT / 2);
    digitalWrite(MOTOR_1_PIN, HIGH);
    digitalWrite(MOTOR_3_PIN, HIGH);
    delay(DIT);
    digitalWrite(MOTOR_3_PIN, LOW);
    delay(DAH - DIT);
  } else if (x == '1') {
    digitalWrite(MOTOR_2_PIN, HIGH);
    delay(DAH);
    digitalWrite(MOTOR_2_PIN, LOW);
    delay(DIT / 2);
    digitalWrite(MOTOR_2_PIN, HIGH);
    delay(DIT);
    digitalWrite(MOTOR_2_PIN, LOW);
    delay(DIT / 2);
    digitalWrite(MOTOR_2_PIN, HIGH);
    digitalWrite(MOTOR_3_PIN, HIGH);
    delay(DIT);
    digitalWrite(MOTOR_3_PIN, LOW);
    delay(DAH - DIT);
  } else if (x == '9') {
    digitalWrite(MOTOR_1_PIN, HIGH);
    delay(DIT);
    digitalWrite(MOTOR_1_PIN, LOW);
    delay(DIT / 2);
    digitalWrite(MOTOR_1_PIN, HIGH);
    delay(DAH);
    digitalWrite(MOTOR_1_PIN, LOW);
    delay(DIT / 2);
    digitalWrite(MOTOR_1_PIN, HIGH);
    digitalWrite(MOTOR_3_PIN, HIGH);
    delay(DIT);
    digitalWrite(MOTOR_3_PIN, LOW);
    delay(DAH - DIT);
  } else if (x == '0') {
    digitalWrite(MOTOR_2_PIN, HIGH);
    delay(DIT);
    digitalWrite(MOTOR_2_PIN, LOW);
    delay(DIT / 2);
    digitalWrite(MOTOR_2_PIN, HIGH);
    delay(DAH);
    digitalWrite(MOTOR_2_PIN, LOW);
    delay(DIT / 2);
    digitalWrite(MOTOR_2_PIN, HIGH);
    digitalWrite(MOTOR_3_PIN, HIGH);
    delay(DIT);
    digitalWrite(MOTOR_3_PIN, LOW);
    delay(DAH - DIT);
  }
  digitalWrite(MOTOR_1_PIN, LOW);
  digitalWrite(MOTOR_2_PIN, LOW);
  digitalWrite(MOTOR_3_PIN, LOW);
  delay(DIT / 2);
}

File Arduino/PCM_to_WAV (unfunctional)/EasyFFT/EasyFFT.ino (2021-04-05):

/*
  //Example data:
  int data[64]={14, 30, 35, 34, 34, 40, 46, 45, 30, 4,  -26,  -48,  -55,  -49,  -37,
  -28,  -24,  -22,  -13,  6,  32, 55, 65, 57, 38, 17, 1,  -6, -11,  -19,  -34,
  -51,  -61,  -56,  -35,  -7, 18, 32, 35, 34, 35, 41, 46, 43, 26, -2, -31,  -50,
  -55,  -47,  -35,  -27,  -24,  -21,  -10,  11, 37, 58, 64, 55, 34, 13, -1, -7};
*/


//---------------------------------------------------------------------------//
byte sine_data [91] =
{
  0,
  4,    9,    13,   18,   22,   27,   31,   35,   40,   44,
  49,   53,   57,   62,   66,   70,   75,   79,   83,   87,
  91,   96,   100,  104,  108,  112,  116,  120,  124,  127,
  131,  135,  139,  143,  146,  150,  153,  157,  160,  164,
  167,  171,  174,  177,  180,  183,  186,  189,  192,  195,       //Paste this at top of program
  198,  201,  204,  206,  209,  211,  214,  216,  219,  221,
  223,  225,  227,  229,  231,  233,  235,  236,  238,  240,
  241,  243,  244,  245,  246,  247,  248,  249,  250,  251,
  252,  253,  253,  254,  254,  254,  255,  255,  255,  255
};
float f_peaks[5]; // top 5 frequencies peaks in descending order
//---------------------------------------------------------------------------//


void setup()
{
  Serial.begin(250000);
}


void loop() {

  /*
    //example
    FFT(data,64,100);        //to get top five value of frequencies of X having 64 sample at 100Hz sampling
    Serial.println(f_peaks[0]);
    Serial.println(f_peaks[1]);
    delay(99999);
  */


  /*
    after ruing above FFT(), frequencies available at f_peaks[0],f_peaks[1],f_peaks[2],f_peaks[3],f_peaks[4],
  */
}



//-----------------------------FFT Function----------------------------------------------//

float FFT(int in[], int N, float Frequency)
{
  /*
    Code to perform FFT on arduino,
    setup:
    paste sine_data [91] at top of program [global variable], paste FFT function at end of program
    Term:
    1. in[]     : Data array,
    2. N        : Number of sample (recommended sample size 2,4,8,16,32,64,128...)
    3. Frequency: sampling frequency required as input (Hz)

    If sample size is not in power of 2 it will be clipped to lower side of number.
    i.e, for 150 number of samples, code will consider first 128 sample, remaining sample  will be omitted.
    For Arduino nano, FFT of more than 128 sample not possible due to mamory limitation (64 recomended)
    For higher Number of sample may arise Mamory related issue,
    Code by ABHILASH
    Contact: abhilashpatel121@gmail.com
    Documentation:https://www.instructables.com/member/abhilash_patel/instructables/
    2/3/2021: change data type of N from float to int for >=256 samples
  */

  unsigned int data[13] = {1, 2, 4, 8, 16, 32, 64, 128, 256, 512, 1024, 2048};
  int a, c1, f, o, x;
  a = N;

  for (int i = 0; i < 12; i++)          //calculating the levels
  {
    if (data[i] <= a) {
      o = i;
    }
  }

  int in_ps[data[o]] = {};   //input for sequencing
  float out_r[data[o]] = {}; //real part of transform
  float out_im[data[o]] = {}; //imaginory part of transform

  x = 0;
  for (int b = 0; b < o; b++)              // bit reversal
  {
    c1 = data[b];
    f = data[o] / (c1 + c1);
    for (int j = 0; j < c1; j++)
    {
      x = x + 1;
      in_ps[x] = in_ps[j] + f;
    }
  }


  for (int i = 0; i < data[o]; i++)     // update input array as per bit reverse order
  {
    if (in_ps[i] < a)
    {
      out_r[i] = in[in_ps[i]];
    }
    if (in_ps[i] > a)
    {
      out_r[i] = in[in_ps[i] - a];
    }
  }


  int i10, i11, n1;
  float e, c, s, tr, ti;

  for (int i = 0; i < o; i++)                             //fft
  {
    i10 = data[i];            // overall values of sine/cosine  :
    i11 = data[o] / data[i + 1]; // loop with similar sine cosine:
    e = 360 / data[i + 1];
    e = 0 - e;
    n1 = 0;

    for (int j = 0; j < i10; j++)
    {
      c = cosine(e * j);
      s = sine(e * j);
      n1 = j;

      for (int k = 0; k < i11; k++)
      {
        tr = c * out_r[i10 + n1] - s * out_im[i10 + n1];
        ti = s * out_r[i10 + n1] + c * out_im[i10 + n1];

        out_r[n1 + i10] = out_r[n1] - tr;
        out_r[n1] = out_r[n1] + tr;

        out_im[n1 + i10] = out_im[n1] - ti;
        out_im[n1] = out_im[n1] + ti;

        n1 = n1 + i10 + i10;
      }
    }
  }

  /*
    for(int i=0;i<data[o];i++)
    {
    Serial.print(out_r[i]);
    Serial.print("\t");                                     // un comment to print RAW o/p
    Serial.print(out_im[i]); Serial.println("i");
    }
  */


  //---> here onward out_r contains amplitude and our_in conntains frequency (Hz)
  for (int i = 0; i < data[o - 1]; i++)      // getting amplitude from compex number
  {
    out_r[i] = sqrt(out_r[i] * out_r[i] + out_im[i] * out_im[i]); // to  increase the speed delete sqrt
    out_im[i] = i * Frequency / N;
    /*
      Serial.print(out_im[i]); Serial.print("Hz");
      Serial.print("\t");                            // un comment to print freuency bin
      Serial.println(out_r[i]);
    */
  }




  x = 0;     // peak detection
  for (int i = 1; i < data[o - 1] - 1; i++)
  {
    if (out_r[i] > out_r[i - 1] && out_r[i] > out_r[i + 1])
    { in_ps[x] = i;  //in_ps array used for storage of peak number
      x = x + 1;
    }
  }


  s = 0;
  c = 0;
  for (int i = 0; i < x; i++)      // re arraange as per magnitude
  {
    for (int j = c; j < x; j++)
    {
      if (out_r[in_ps[i]] < out_r[in_ps[j]])
      { s = in_ps[i];
        in_ps[i] = in_ps[j];
        in_ps[j] = s;
      }
    }
    c = c + 1;
  }



  for (int i = 0; i < 5; i++) // updating f_peak array (global variable)with descending order
  {
    f_peaks[i] = out_im[in_ps[i]];
  }



}


float sine(int i)
{
  int j = i;
  float out;
  while (j < 0) {
    j = j + 360;
  }
  while (j > 360) {
    j = j - 360;
  }
  if (j > -1   && j < 91) {
    out = sine_data[j];
  }
  else if (j > 90  && j < 181) {
    out = sine_data[180 - j];
  }
  else if (j > 180 && j < 271) {
    out = -sine_data[j - 180];
  }
  else if (j > 270 && j < 361) {
    out = -sine_data[360 - j];
  }
  return (out / 255);
}

float cosine(int i)
{
  int j = i;
  float out;
  while (j < 0) {
    j = j + 360;
  }
  while (j > 360) {
    j = j - 360;
  }
  if (j > -1   && j < 91) {
    out = sine_data[90 - j];
  }
  else if (j > 90  && j < 181) {
    out = -sine_data[j - 90];
  }
  else if (j > 180 && j < 271) {
    out = -sine_data[270 - j];
  }
  else if (j > 270 && j < 361) {
    out = sine_data[j - 270];
  }
  return (out / 255);
}

//------------------------------------------------------------------------------------//

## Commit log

2021-03-09 Create characteristics and descriptor for Arduino BLE
2021-03-10 Included Motor testing
2021-04-05 Tried PCM to WAV algorithm (failed)
    [EasyFFT.ino, VolumeMeter.ino]
2021-04-05 Implemented Tensorflow model on Arduino (success with low accurracy)
2021-04-05 Implemented second tensor flow model on Arduino (higher but still low accurracy)
    [bye.csv, hello.csv, yes.csv]
2021-04-09 Tested a few more methods for the Arduino microphone
2021-04-10 Completed Arduino text to altered morse
2021-04-10 Completed the app (Added WiFi compatibilities and connection button)
2021-04-10 Updated vibration motor pins
    [arduinoBLE_Connection_setup_V2.ino.ino]
